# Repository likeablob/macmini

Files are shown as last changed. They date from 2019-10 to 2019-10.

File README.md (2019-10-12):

<p align="center">
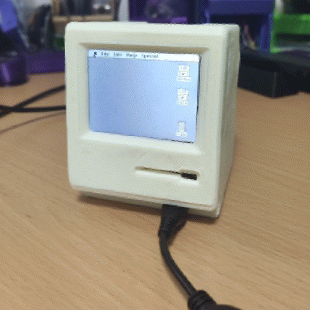
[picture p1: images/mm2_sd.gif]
  
</p>

# Mac(intosh) mini

## Build Instruction
- Print the outer shell.
  - PLA, 0.2 mm, 180 ℃ (See also [./openscad/README.md](./openscad/README.md))
  - `macintosh-mini-part-a.stl` ([stl](./openscad/macintosh-mini-part-a.stl))
  - `macintosh-mini-part-b.stl` ([stl](./openscad/macintosh-mini-part-b.stl))

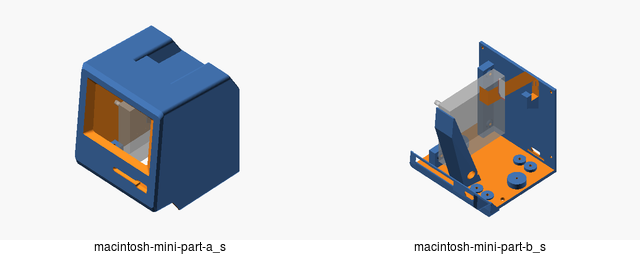
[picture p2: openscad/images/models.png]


- Setup your Orange Pi Zero Plus 2 (H3)
  - Install Armbian Bionic. https://www.armbian.com/orange-pi-zero-plus-2-h3/
  - Then SSH into the device.
```bash
$ sudo apt install -y git tightvncserver

# Install Node.js
$ git clone https://github.com/tj/n /tmp/n && cd /tmp/n && sudo make install
$ sudo n v10

# Install https://github.com/xpertsavenue/WiringOP-Zero
$ cd ~/
$ git clone https://github.com/xpertsavenue/WiringOP-Zero
## Please refer to https://github.com/xpertsavenue/WiringOP-Zero

# Enable SPI1 interface
$ sudo vi /boot/armbianEnv.txt # or use armbian-config
! overlays=spi-spidev analog-codec usbhost2 usbhost3
+ param_spidev_spi_bus=1

# Setup vncserver
$ mkdir ~/.vnc
$ vncpasswd ~/.vnc/passwd

# Install the dependencies & config files
$ git clone https://github.com/likeablob/macmini ~/macmini
$ cd ~/macmini
$ sudo ./install.sh

# Copy your assets
$ cp /path/to/vmac.rom ~/macmini/minivmac/vMac.ROM # Mini vMac ROM file
$ cp /path/to/vmac.dsk ~/macmini/minivmac/system.dsk # Mini vMac disk file
$ cp /path/to/.basilisk_ii_prefs ~/.basilisk_ii_prefs # Basilisk II config file
$ cp /path/to/macboot.wav ~/macmini/macboot.wav # Boot sound (optional)

# Reboot to apply the settings
$ sudo reboot now

# Select LineOut as the default sink
$ pacmd list-sinks | grep -e 'name:' -e 'index:'
  index: 0
	  name: <alsa_output.platform-1c22c00.codec.analog-mono> # LineOut
* index: 1
	  name: <alsa_output.platform-soc_sound.stereo-fallback> # HDMI
$ pactl set-default-sink 0 # or use `DISPLAY=:1 pavucontrol` and `alsamixer` to adjust volume
```
- [Tips]: Here is my working [.basilisk_ii_prefs](basilisk_ii_prefs.md).
  
- Wire the display & USB boards to the OPi

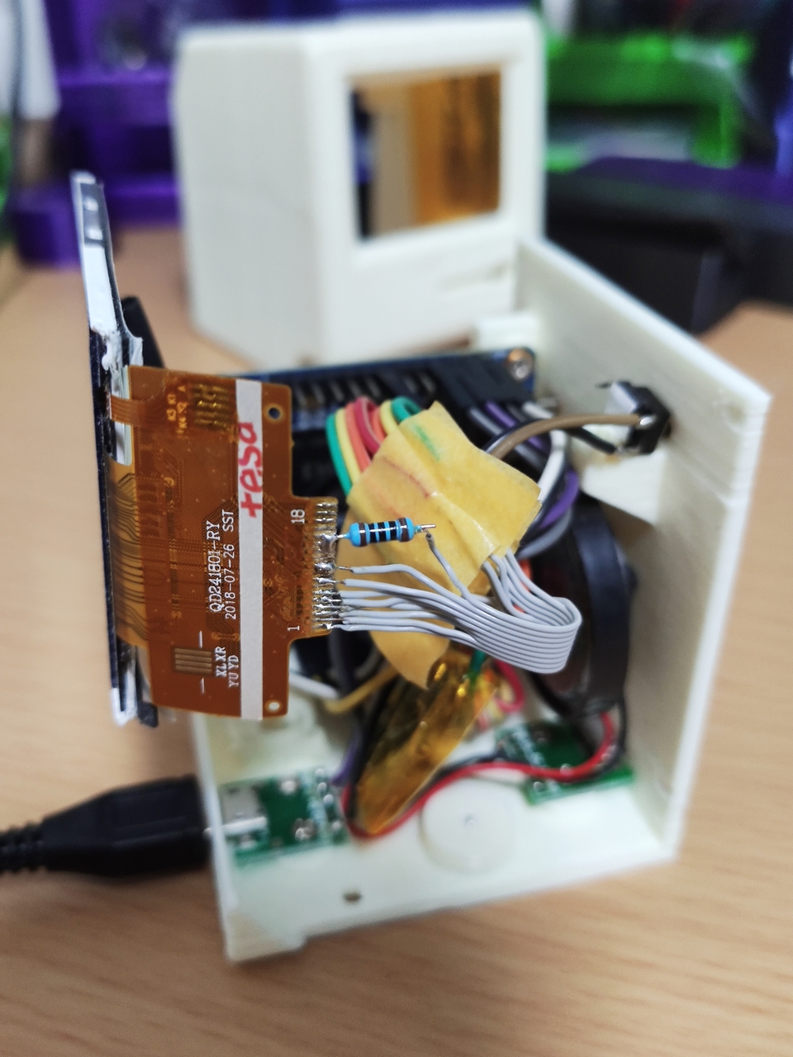
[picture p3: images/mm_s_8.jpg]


| OPi | Peripherals |
| --- | --- |
| PA15/SPI1_MOSI | LCD MOSI |
| PA16/SPI1_MISO | LCD MISO |
| PA14/SPI1_CLK  | LCD CLK |
| PA13/SPI1_CS | LCD CS |
| PS12 | LCD RESET |
| PA11 | LCD DC |
| PA06 | Push Switch |
| GND | Push Switch |
| USB-DP2 | USB (Front) Data+ |
| USB-DM2 | USB (Front) Data- |
| 5V | USB (Front/Rear) 5V |
| GND | USB (Front/Rear) GND |
| LINEOUTL | (Optional) Amplifier Input |

- [Tips]: Pinout can be found below.
  - OPiZero
    - https://linux-sunxi.org/Xunlong_Orange_Pi_Zero_Plus
    - http://www.orangepi.org/orangepibbsen/forum.php?mod=viewthread&tid=2236
  - LCD (Note that there might be some variants.)
    - [link1](https://www.solidrop.net/product/free-ship-5pc-lot-2-4inch-spi-tft-lcd-screen-18pin-240-320-color-lcd-drive-ic-ili9341-4io-only-for-stm32-mcu-raspberry-pi.html) [link2](https://github.com/myelin/tiny-tft/blob/master/TJC-024-9341-18-pin-SPI-240x320-ili9341-2.4-inch-touch/chinese-driver/TJC-024-9341.pdf)
    - [backup](./images/lcd-ili9341-pinout.jpg)

## Basic Concepts
1. At system boot, [`fbtft_device`](./config/fbtft.conf) kernel module is loaded and it initializes the LCD as `/dev/fb0`.
2. `nodm` starts an X session and `~/.xinitrc` get executed.
3. `~/.xinitrc` launchs `matchbox-window-manager` and `~/macmini/switcher/*js`.
4. `~/macmini/switcher/index.js` reads the scripts [`~/macmini/switcher/sh.d/*sh`](./switcher/sh.d/) and spawns them one by one when there is a HTTP GET request at `localhost:5501/`.
5. `~/macmini/switcher/gpio-reader.js` watchs the push SW at GPIO7(PA06) and send a request to `localhost:5501/`.

### How does the low-res LCD(320x240) handle 512x384 resolution?
Internally `tightvncserver` and `ssvncviewer` are used to scale the display.
- e.g. [`1_large_minimac.sh`](./switcher/sh.d/1_large_minimac.sh) launches: 
  -  `tightvncserver` to create a virtual display (512x384) at `DISPLAY=:1` (`:5901`)
  -  `minivmac` in `DISPLAY:1`
  -  `ssvncviewer -scale 0.625` in `DISPLAY:0` (By the `-scale` option, low-res LED get upscaled)

## Gallery
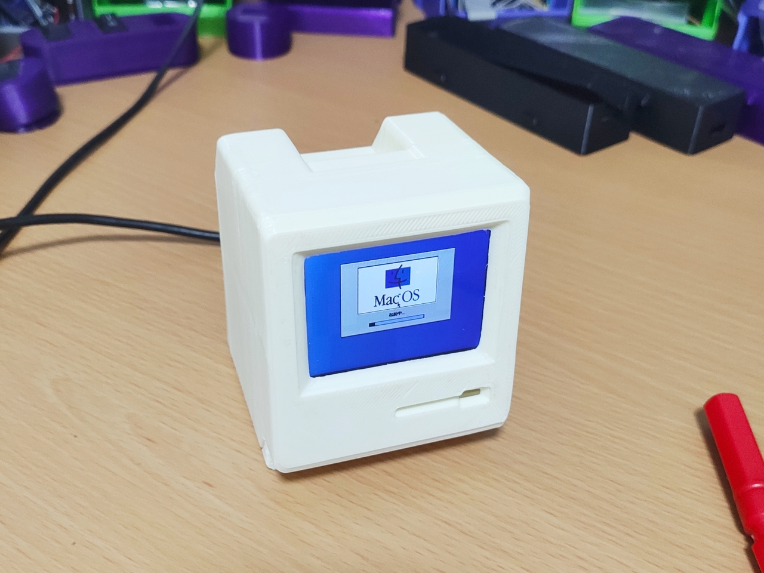
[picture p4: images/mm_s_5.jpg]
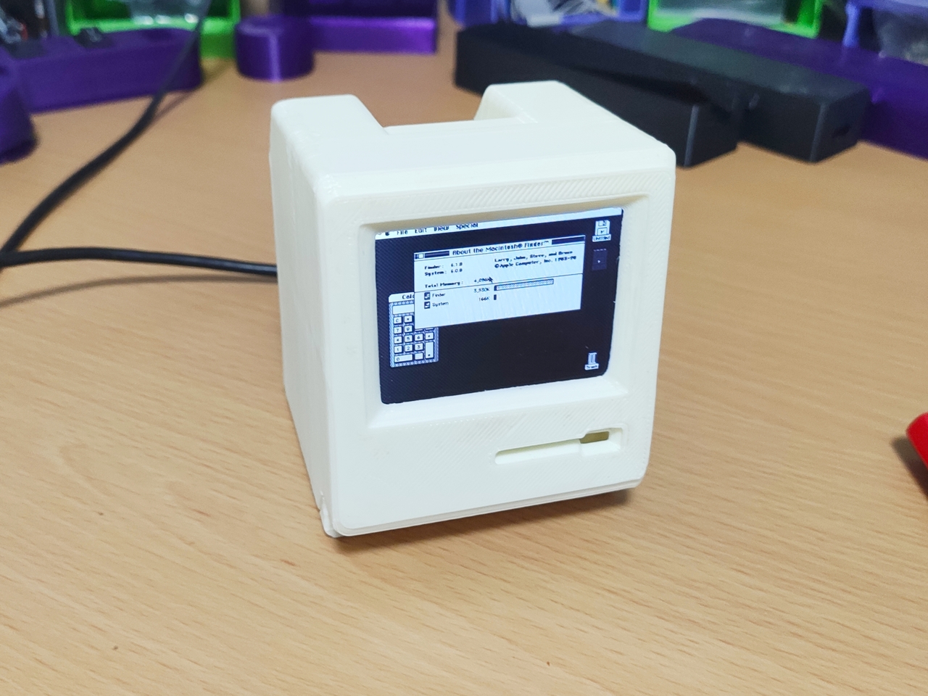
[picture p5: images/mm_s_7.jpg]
|   |   |
| :---: | :---: |
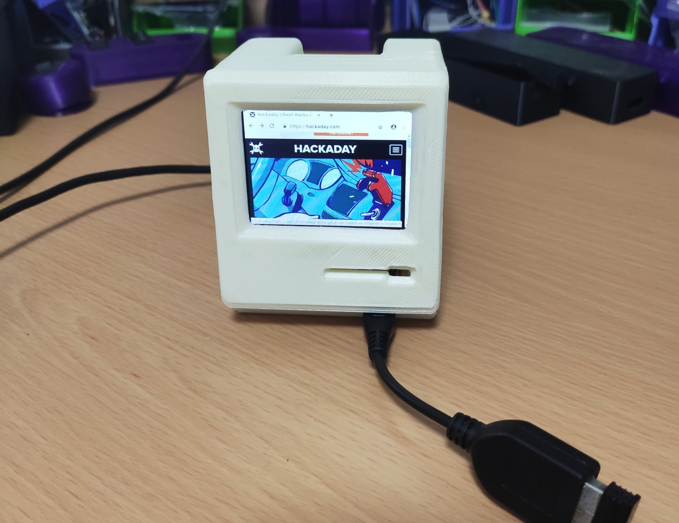
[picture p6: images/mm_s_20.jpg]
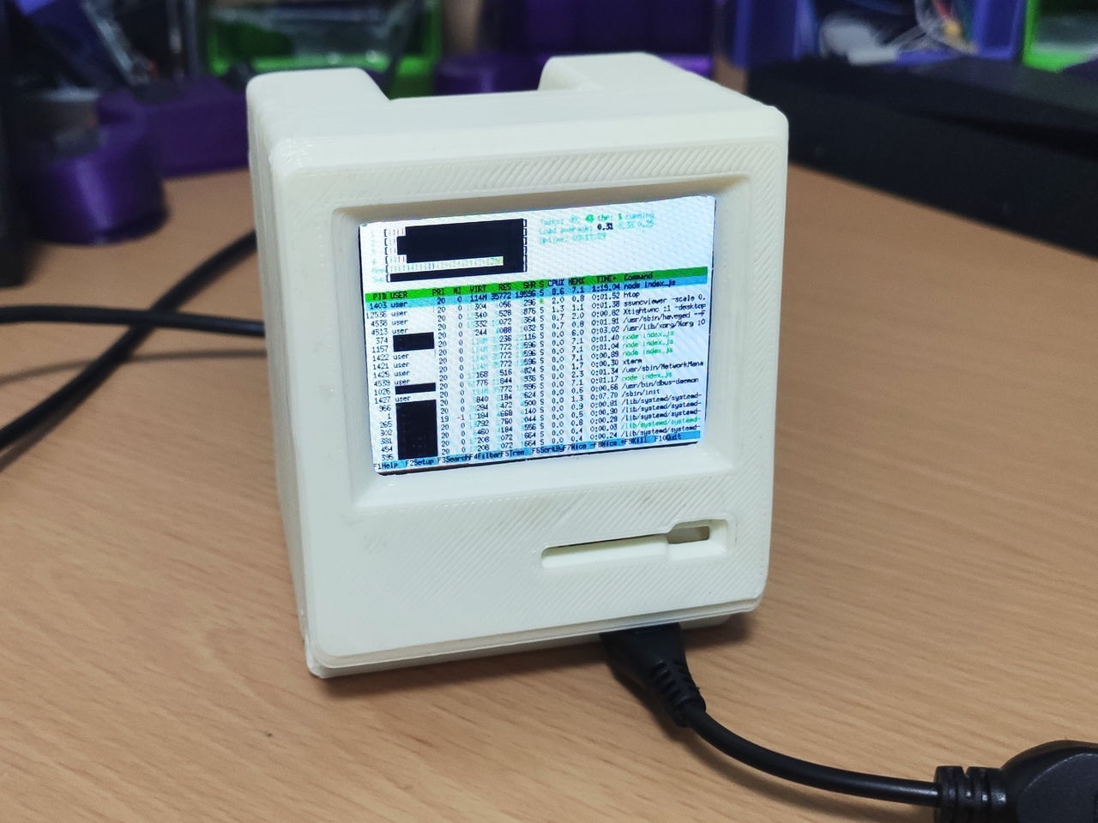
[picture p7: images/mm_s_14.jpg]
|  |  |
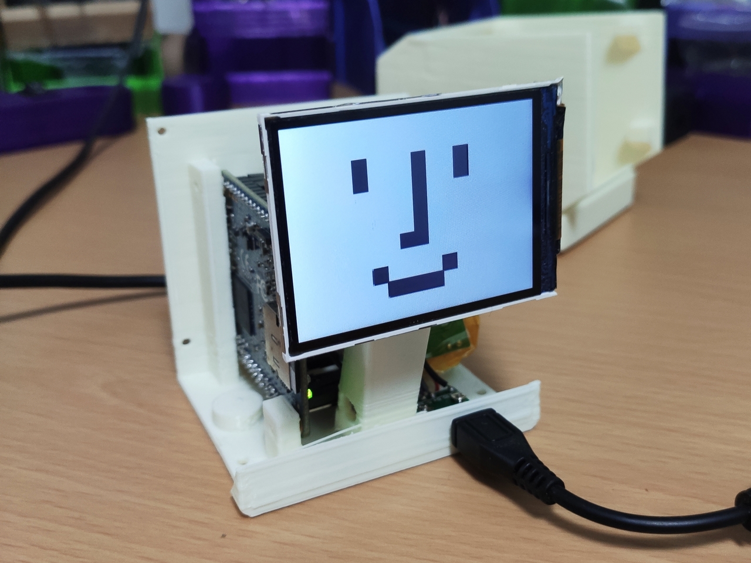
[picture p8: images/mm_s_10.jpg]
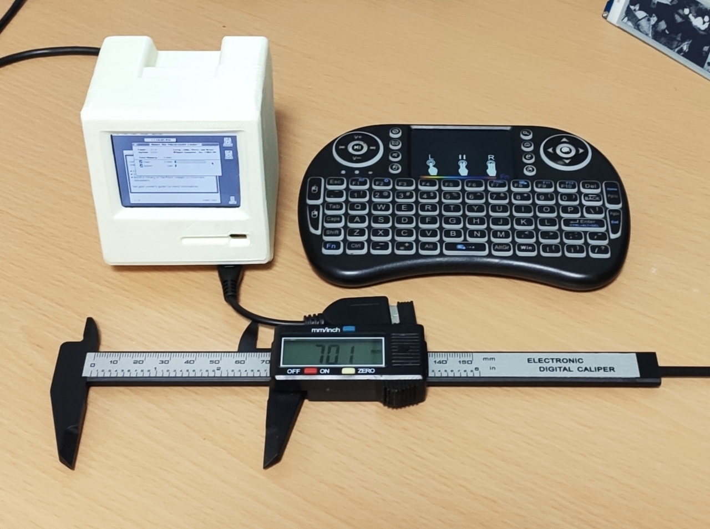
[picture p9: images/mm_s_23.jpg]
|  |  |
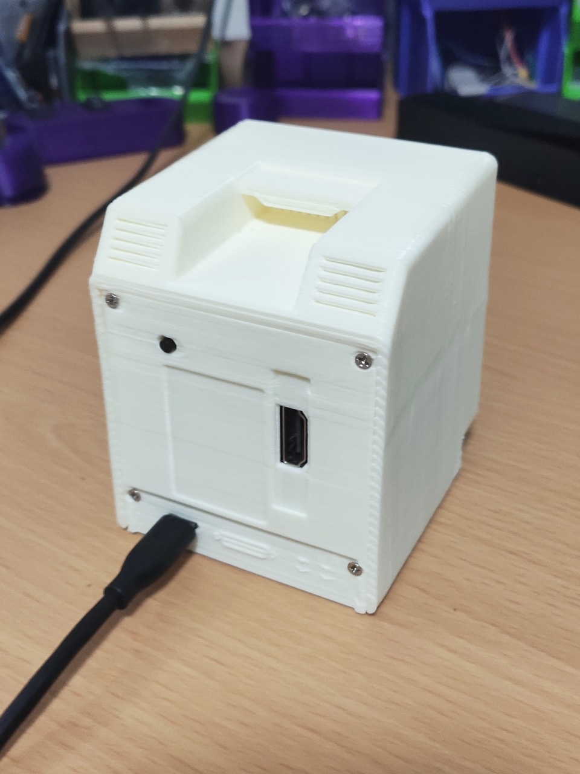
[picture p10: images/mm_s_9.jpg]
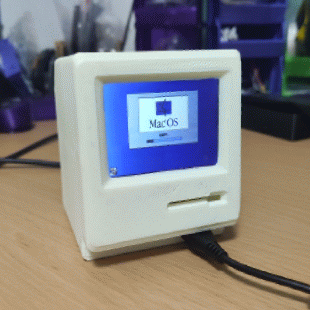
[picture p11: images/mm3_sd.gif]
|   |   |

## BOM
| Name | Quantity | Descriptions |
| --- | :---: | --- |
| OrangePi Zero Plus 2 (H3) | 1 | H5 ver. might work too. |
| 2.4inch SPI Display (ili9341, 320x240, with flat cable) | 1 | |
| Generic micro-USB Breakout Board | 2 | |
| M2 x 6 mm Self Tapping Screw | 16 | |
| D10mm Rounding Magnet | 2 | |
| 7x7 mm Push Switch | 1 | |
| 2W Small Speaker | 1 | (Optional) |
| ClassD Audio Amplifier Board | 1 | (Optional) PAM8403 |

## Acknowledgments
- Mini vMac https://www.gryphel.com/c/minivmac/
- Basilisk II https://basilisk.cebix.net/
- Kudos to all the devs!

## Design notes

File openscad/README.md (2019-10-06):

<p align="center">
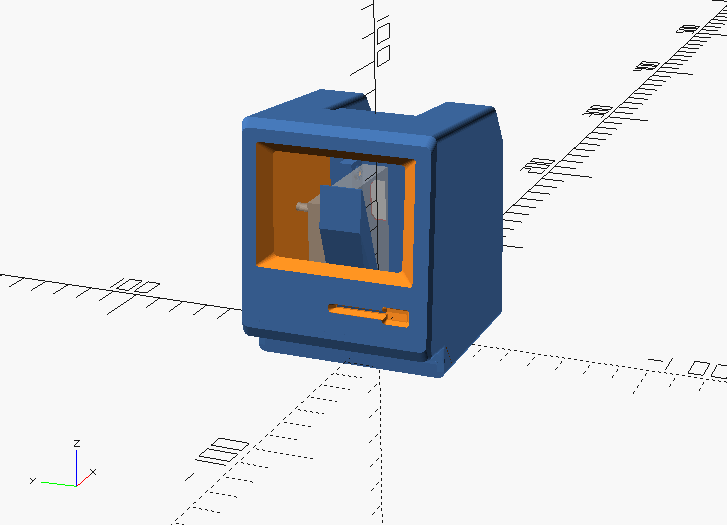
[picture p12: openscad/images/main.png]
  
</p>

## Print conditions
- PLA, 0.2 mm, 180 ℃
- `macintosh-mini-part-a`: Rotate so that the -X(front) side is facing down.



## Dependencies
- [OskarLinde]'s [scad-utils](https://github.com/OskarLinde/scad-utils)
- openscad-nightly (`20181009T230242.gitf3de0e27+2416.1`)

## Build
```sh
$ git submodule update --init --recursive # or git clone --recursive
$ make -j4
```

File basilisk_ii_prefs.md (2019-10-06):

~/.basilisk_ii_prefs
```bash
disk ${/path/to/disk1.dsk}
disk ${/path/to/disk2.dsk}
extfs ${/path/to/your/home/dir}
screen win/512/384
seriala /dev/ttyS5
serialb /dev/ttyS6
ether slirp
udptunnel false
udpport 6066
rom ${/path/to/mac.rom}
bootdrive 0
bootdriver 0
ramsize 33554432
frameskip 0
modelid 5
cpu 3
fpu false
nocdrom true
nosound false
noclipconversion false
nogui false
jit true
jitfpu true
jitdebug false
jitcachesize 2048
jitlazyflush true
jitinline true
keyboardtype 5
keycodes false
mousewheelmode 1
mousewheellines 3
dsp /dev/dsp
mixer /dev/mixer
idlewait true
```

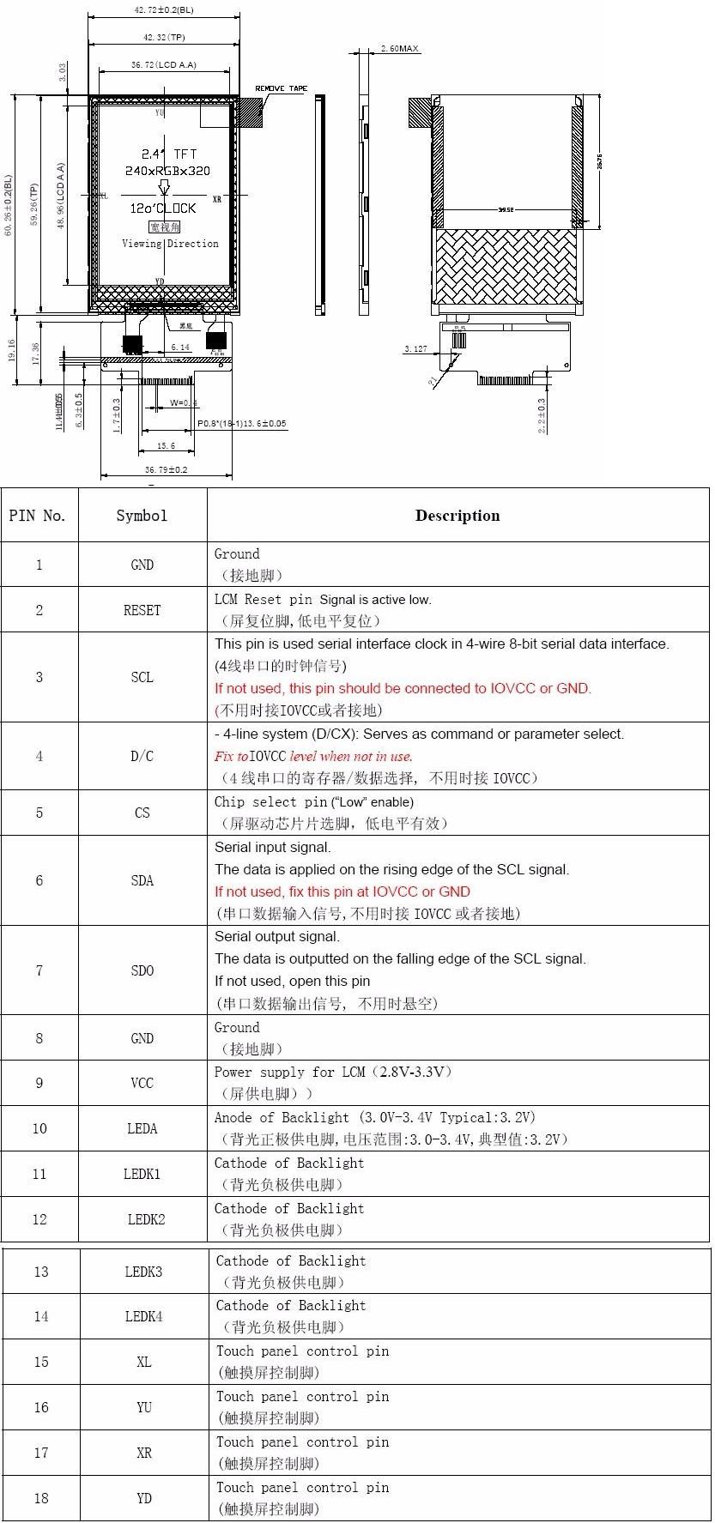
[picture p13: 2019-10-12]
images/lcd-ili9341-pinout.jpg

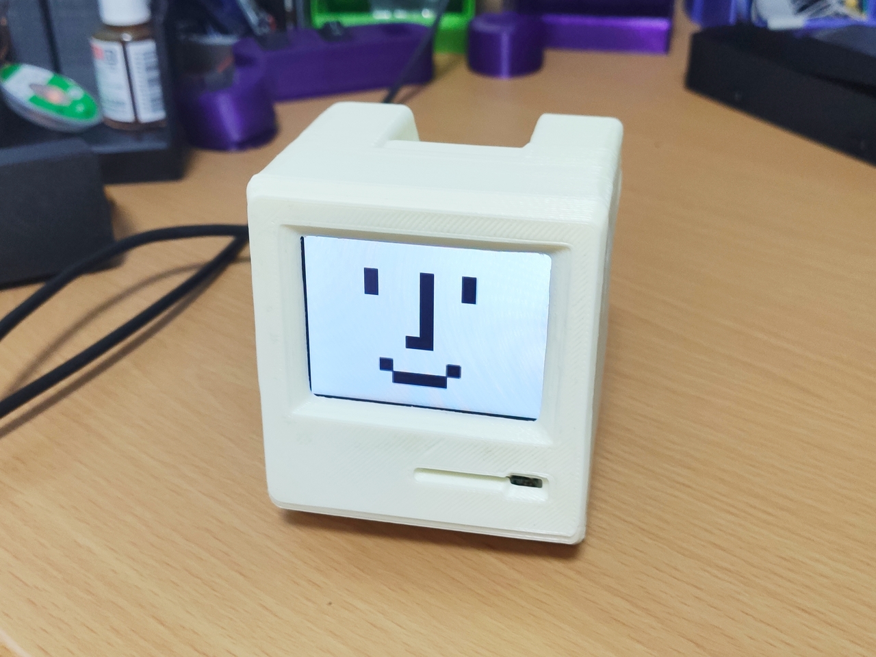
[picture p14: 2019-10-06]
images/mm_s_6.jpg

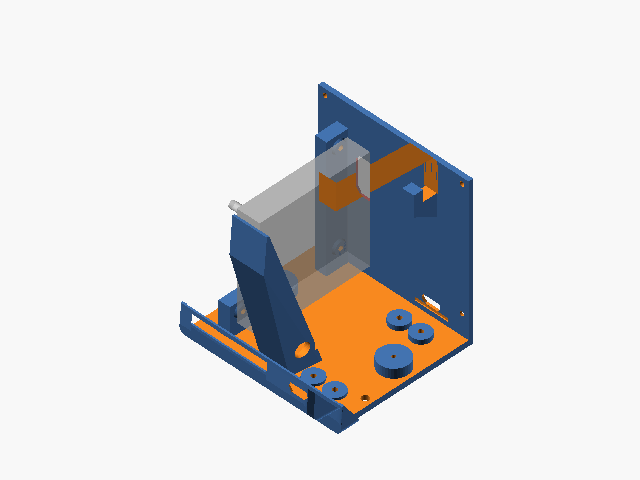
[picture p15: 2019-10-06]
openscad/images/macintosh-mini-part-b_s.png

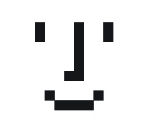
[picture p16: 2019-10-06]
images/macface.png

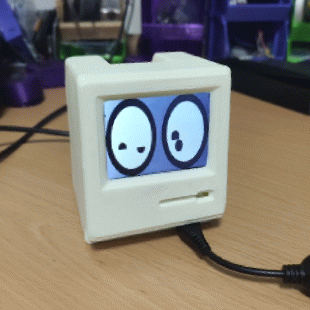
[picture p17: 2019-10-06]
images/mm1_sd.gif

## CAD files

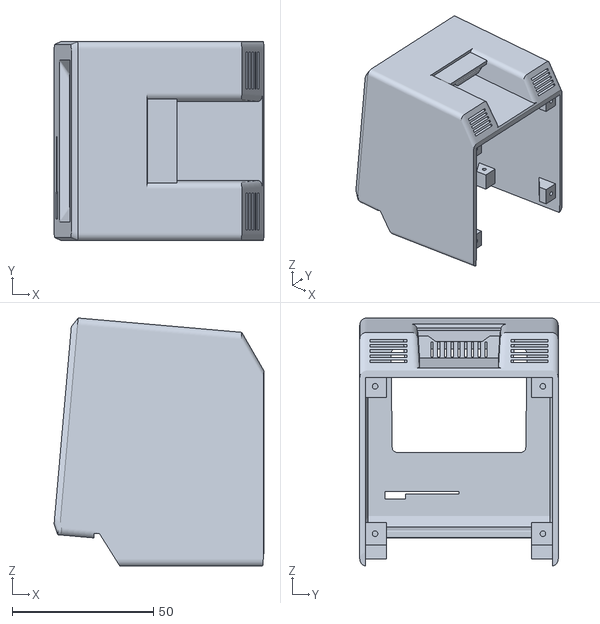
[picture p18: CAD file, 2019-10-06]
openscad/macintosh-mini-part-a.stl
74.3 x 70.3 x 87.8

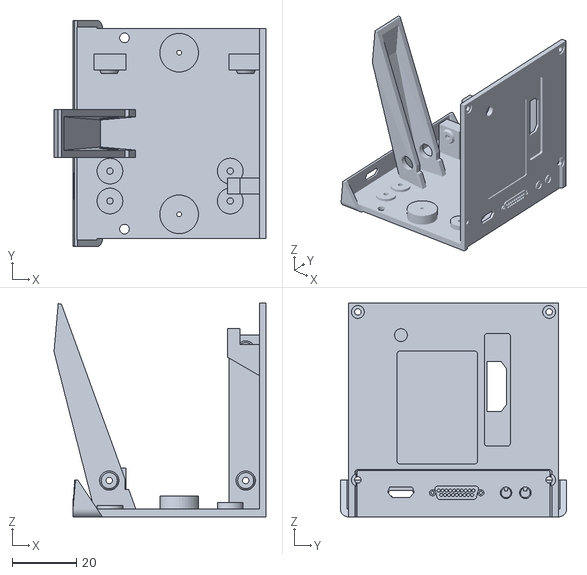
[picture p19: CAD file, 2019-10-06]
openscad/macintosh-mini-part-b.stl
65.9 x 70.3 x 66.5

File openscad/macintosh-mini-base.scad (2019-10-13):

$fn=40;
include <scad-utils/morphology.scad>

WH_RATIO = 22.7/29.2;
DH_RATIO = 46.0/63.4;

BODY_Z = 90;
BODY_X = BODY_Z * WH_RATIO;
BODY_Y = BODY_Z * DH_RATIO;

module copy_mirror(vec=[0,1,0]){
    children();
    mirror(vec) children();
}

module base(mscale=1) {
  difference() {
    hull() {
      // upper
      translate([0, 0, (BODY_X)/2 + (BODY_Z-BODY_X)/2])
      rotate([0, 5, 0])
      cube(size=[BODY_X, BODY_Y, BODY_X], center=true);

      // lower
      translate([0, 0, (BODY_Z-BODY_X)/2])
      cube(size=[BODY_X, BODY_Y, BODY_Z-BODY_X], center=true);

      // display
      rotate([0, 5, 0])
      translate([-BODY_X/2-6, 0, (BODY_Z-BODY_X)/2-1])
      translate([0, 0, BODY_X/2])
      cube(size=[0.1, BODY_Y*0.97, BODY_X*0.93], center=true);
    }

    // under the display
    minkowski() {
      UD_Z = (BODY_Z-BODY_X)/2*0.6;
      translate([-BODY_Y/2-10/2, 0, UD_Z-1.5])
      hull() {
        rotate([0, 5, 0])
        cube(size=[BODY_Y*0.2+10, BODY_Y+1, UD_Z*2], center=true);

        /* translate([BODY_Y*0.2/2+8, 0, -UD_Z])
        rotate([90, 0, 0])
        cylinder(d=0.01, h=BODY_Y+1, center=true); */
        translate([BODY_Y*0.2/2+1, 0, -UD_Z])
        rotate([90, 0, 0])
        cylinder(d=0.01, h=BODY_Y+1, center=true);
      }

      rotate([90, 0, 0])
      cylinder(d=1, h=10, center=true);
    }

    // top mizo
    translate([BODY_X*0.4, 0, BODY_Z-BODY_Z*0.27])
    rotate([0, 5, 0])
    scale([mscale, mscale, mscale])
    linear_extrude(height=BODY_Z*0.3, scale=1.1,  center=false, convexity=10, twist=0)
    square(size=[BODY_X, BODY_Y/2], center=true);

    // back edge
    translate([BODY_Y, 0, BODY_X/2 + BODY_Z*0.5])
    rotate([0, 60, 0])
    cube(size=[BODY_X, BODY_Y+3, BODY_X], center=true);

    // back
    translate([BODY_X/2+BODY_X*0.1/2-1, 0, (BODY_Z)/2])
    cube(size=[BODY_X*0.1, BODY_Y*1.2, BODY_Z], center=true);

    // side edge
    *copy_mirror([0,1,0])
    translate([-BODY_X/2, BODY_Y/2, 0])
    translate([0, 0, BODY_Z/2*1.1])
    rotate([0, 5, 0])
    rotate([0, 0, 60])
    cube(size=[5, 5, BODY_Z], center=true);
  }
}

THICK=-5;

// variables for partB
OPIZ_X = 48;
OPIZ_Y = 46;
OPIZ_Z = 10;

OPI_HOLE_POS = 2.8;

HDMI_Z=5.5;
HDMI_Y=15;

OPIZ_HLD_Z = BODY_Z*0.6;
OPIZ_HLD_Y = 5;
OPIZ_HLD_X = 10;

OPIZ_OFFSET_Z = 6;
OPIZ_OFFSET_X = -1.5;

BACKPANEL_X = 1.0;

module partB() {
  difference() {
    union() {
      difference() {
        intersection(){
          difference(){
            minkowski() {
              base();
              rotate([0, 90, 0])
              cylinder(d=5, h=0.01, center=true);
            }
            // inner space
            difference() {
              translate([-0.5, 0, 0])
              scale([0.95, 1, 1])
              resize([BODY_X-THICK, 0, 0], auto=[false, true, true])
              base(1.15);

              translate([BODY_X/2+10/2-3, 0, 0])
              cube(size=[10, BODY_Y*2, BODY_Z*2], center=true);
            }

            copy_mirror([0,1,0])
            translate([BODY_X/2-10, BODY_Y*0.91/2, BODY_Z*0.68])
            rotate([0, 90, 0]){
              screw(2);
              translate([0, 0, 8.5])
              screw(4);
            }

            copy_mirror([0,1,0])
            translate([BODY_X/2-10, BODY_Y*0.91/2, BODY_Z*0.1])
            rotate([0, 90, 0]){
              screw(2);
              translate([0, 0, 8.5])
              screw(4);
            }

            copy_mirror([0,1,0])
            translate([-BODY_X*0.2, BODY_Y*0.91/2, BODY_Z*0.1/3])
            union(){
              screwB(3);
              translate([0, 0, -15])
              screwB(4);
            }

          }

          // partB

          union() {
            H2 = (BODY_Z-BODY_X);
            Y=BODY_Y-THICK-4-1;
            // front
            hull() {
              translate([-(BODY_X/2 + BODY_Y*0.2)/2-1, 0, H2/2-2])
              cube(size=[1, Y+8, 2], center=true);

              translate([-(BODY_X/2 + BODY_Y*0.2)/2-1.3, 0, -2])
              cube(size=[2, Y+8, 2], center=true);

              translate([-(BODY_X/2)/2, 0, -4])
              cube(size=[2, Y+8, 2], center=true);
            }

            // bottom
            cube(size=[BODY_X, Y, BODY_X*0.1], center=true);

            // back
            translate([(BODY_X/2), 0, BODY_Z*0.75/2-1-0.3])
            cube(size=[BODY_X*0.2, Y, BODY_Z*0.70], center=true);
          }

        }

        // hdmi
        color("red")
        translate([BODY_X/2-OPIZ_X/2-3, BODY_Y/3.5, OPIZ_Y/2 + OPIZ_OFFSET_Z])
        rotate([90, 0, 0])
        translate([OPIZ_X/2+3, OPIZ_Y/2-HDMI_Y/2-6.5, 2.5])
        hdmi(0.3);

        // micro usb for power
        translate([BODY_X/2-USBM_BOARD[0]/2+OPIZ_OFFSET_X-1.1, -BODY_Y/4, 2])
        rotate([0, 0, 180])
        usbm_board(0.2);

        // micro usb for keyboards
        translate([-BODY_X*0.1-USBM_BOARD[0]/2-2, -BODY_Y/4,1])
        usbm_board(0.2);

        // switch
        translate([BODY_X/2, -BODY_Y/4, BODY_Z*0.6])
        rotate([0, 90, 0])
        linear_extrude(height=10, center=true, convexity=10, twist=0)
        circle(d=4);

      } // diff

      // opi holder
      translate([OPIZ_OFFSET_X, 0, 0])
      difference() {
        union() {
          translate([BODY_X/2-OPIZ_HLD_X/2-1, OPIZ_HLD_Y/2 + BODY_Y/3.5  + 1, OPIZ_HLD_Z/2])
          cube(size=[OPIZ_HLD_X, OPIZ_HLD_Y, OPIZ_HLD_Z], center=true);

          translate([BODY_X/2+OPIZ_HLD_X/2-5-OPIZ_X, OPIZ_HLD_Y/2 + BODY_Y/3.5  + 1, OPIZ_HLD_Z/4.5/2])
          cube(size=[OPIZ_HLD_X, OPIZ_HLD_Y, OPIZ_HLD_Z/4], center=true);

          // screw base A
          translate([BODY_X/2-OPIZ_X/2-3, BODY_Y/3.5, OPIZ_Y/2 + OPIZ_OFFSET_Z])
          rotate([90, 0, 0])
          mirror_y()
          translate([OPIZ_X/2-OPI_HOLE_POS, OPIZ_Y/2-OPI_HOLE_POS, -1])
          cylinder(d=6, h=1, d2=5, center=!true);

          // screw base B
          translate([BODY_X/2-OPIZ_X/2-3, BODY_Y/3.5, OPIZ_Y/2 + OPIZ_OFFSET_Z])
          rotate([90, 0, 0])
          mirror([1, 0, 0])
          mirror([0, 1, 0])
          translate([OPIZ_X/2-OPI_HOLE_POS, OPIZ_Y/2-OPI_HOLE_POS, -1])
          cylinder(d=6, h=1, d2=5, center=!true);
        }

        // screws A
        translate([BODY_X/2-OPIZ_X/2-3, BODY_Y/3.5, OPIZ_Y/2 + OPIZ_OFFSET_Z])
        rotate([90, 0, 0])
        mirror_y()
        translate([OPIZ_X/2-OPI_HOLE_POS, OPIZ_Y/2-OPI_HOLE_POS, -1])
        cylinder(d=2, h=10, center=true);

        // screws B
        translate([BODY_X/2-OPIZ_X/2-3, BODY_Y/3.5, OPIZ_Y/2 + OPIZ_OFFSET_Z])
        rotate([90, 0, 0])
        mirror([1, 0, 0])
        mirror([0, 1, 0])
        translate([OPIZ_X/2-OPI_HOLE_POS, OPIZ_Y/2-OPI_HOLE_POS, -1])
        cylinder(d=2, h=10, center=true);

      }

      // micro usb for power - screws
      translate([BODY_X/2-USBM_BOARD[0]/2+OPIZ_OFFSET_X-1.1, -BODY_Y/4, 0])
      rotate([0, 0, 180])
      usbm_board_screws(d=8, h=2, center=false);

      // micro usb for keyboards - screws
      translate([-BODY_X*0.1-USBM_BOARD[0]/2-2, -BODY_Y/4, 0])
      usbm_board_screws(d=8, h=1, center=false);

      // magnets - holder
      mirror_y()
      translate([7, BODY_Y/2.6, 0])
      cylinder(d=12, h=4, center=!true);
      } // union

      // micro usb for power
      translate([BODY_X/2-USBM_BOARD[0]/2+OPIZ_OFFSET_X-1.1, -BODY_Y/4, -2.2])
      rotate([0, 0, 180])
      usbm_board_screws(d=2, h=5, center=false);

      // micro usb for keyboards
      translate([-BODY_X*0.1-USBM_BOARD[0]/2-2, -BODY_Y/4, -2.2])
      usbm_board_screws(d=2, h=5, center=false);

      // magnets - holder
      mirror_y()
      translate([7, BODY_Y/2.6, -2.6]) {
        cylinder(d=11, h=3+0.01, center=!true);
        translate([0, 0, 3])
        cylinder(d=11, d2=3, h=2, center=!true);
      }

      // magnets - holder
      mirror_y()
      translate([7, BODY_Y/2.6, -2.6]) {
        cylinder(d=1.5, h=10, center=!true);
      }

      // back panel A
      color("red")
      translate([BODY_X/2+10/2-1-BACKPANEL_X, BODY_Y/3.5-5, OPIZ_Y/2+14])
      rotate([0, 90, 0])
      linear_extrude(height=10, center=true, convexity=10, twist=0)
      rounding(0.8)
      square(size=[35, 8], center=true);

      // back panel B
      color("red")
      translate([BODY_X/2+10/2-1-BACKPANEL_X, 0, 2])
      rotate([0, 90, 0])
      linear_extrude(height=10, center=true, convexity=10, twist=0, scale=1.2)
      rounding(0.8)
      square(size=[20, 60], center=true);

      // back panel C
      color("red")
      translate([BODY_X/2+10/2-1.5, -5, BODY_Z*0.35])
      rotate([0, 90, 0])
      linear_extrude(height=10, center=true, convexity=10, twist=0)
      rounding(0.8)
      square(size=[35, 25], center=true);

    }


    module pport(y=10, z=3) {
      rotate([0, 90, 0])
      linear_extrude(height=1.0, center=true, convexity=10, twist=0)
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

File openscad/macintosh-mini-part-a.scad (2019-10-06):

include <macintosh-mini-base.scad>

partA();

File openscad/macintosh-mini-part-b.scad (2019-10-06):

include <macintosh-mini-base.scad>

partB();

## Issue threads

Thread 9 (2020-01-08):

Resistor

pmar146, 2020-01-08:
The size of the resistor isn't clear in the image. Can you tell me what size you used?

likeablob, 2020-01-10:
@pmar146 Hi,  I'm using a 100 ohm resistor. That is a current-limiting resistor to adjust screen brightness, so the optimum value may vary.

pmar146, 2020-01-11:
Hi and thank your for the reply. I have printed the case and have a screen. Sadly my orange Pi is not the same as yours, so I am waiting on my new one to arrive. I love this little Mac. It is very cute.

________________________________
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

likeablob, 2020-01-11:
My pleasure.Thank you for your feedback :+1:
(I'd be happy if you could share the photos of your Mac.)

FYI, The Orange Pi used here is [`Orange Pi Zero +2 H3`](https://www.armbian.com/orange-pi-zero-plus-2-h3/). For `Orange Pi Zero +2 H5` (which has an arm64 CPU), you might need to recompile `minivmac`, at least.

pmar146, 2020-02-24:
Hi there again,
I got my new OPi last week. Sadly they sent an H5 instead of H3. You mentioned I need to recompile minivmac. I have followed all your project on my Opi and I see you have 2 minivmacs in the minivmac folder. I haven’t tried to run them yet. I have just copied all my assets to the folder and that is where I stopped on your project on GitHub. I am not sure where to turn next. I haven’t connected my lcd yet. Just ssh through putty to get the job done so far.

I tried to upload pictures of my one, but  I can’t put them on github. Where is the best place to post them.

Cheers and best wishes

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

likeablob, 2020-02-25:
@pmar146  Hi! Oops, I completely forgot to upload the source tarballs. Let me dig in my working dir...

Anyway, you can use the original author's [Mini vMac Variations Service](https://www.gryphel.com/c/minivmac/var_serv.html) to generate a tarball and follow [Build instruction](https://www.gryphel.com/c/minivmac/build.html) to compile it.

Also, even if pre-compiled `minivmac` doesn't run on your H5 OPiZero, the other shell scripts (apps) for example [sh.d/4_terminal.sh](https://github.com/likeablob/macmini/blob/master/switcher/sh.d/4_terminal.sh) probably work well. So you may see `xterm` launched once you've [correctly wired up the LCD and executed `install.sh`](https://github.com/likeablob/macmini#build-instruction). To debug these scripts, you might want to do as follows.

```bash
$ cd ~/macmini/switcher
$ npm start # Start `switcher` script manually
$ curl -v http://localhost:5501/ # Switch to a next script
or
$ cd ~/macmini/switcher/sh.d
$ sh 4_terminal.sh # The other scripts can be executed in the same way.
```

(BTW, to upload pictures, try to drag&drop a file to GitHub's comment box.

pmar146, 2020-02-25:
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

Here is my print of the case. I have been thoroughly enjoying this project.

likeablob, 2020-02-29:
@pmar146 Hi, I've finally pushed [the tarballs to here](https://github.com/likeablob/macmini/tree/master/minivmac).

Thank you. Nicely printed! (BTW, Have you printed `macintosh-mini-part-a.stl` (a upper part) upside down? That part can be printed w/o supports when it's rotated so that the -X(front) side is facing down.

pmar146, 2020-03-03:
Hi likeablob
I haven't printed the part that way round. I might give it a go when I get the pi sorted out. Thank you for the compliments too. Incidentally, this was the first print I have done with supports, so I am happy with it.

Thank you for posting the tar balls. I am downloading now.

I must compliment you on your soldering. This is not an easy thing to do on such a small ribbon cable.

Cheers and thanks

pmar146, 2020-03-03:
Hi likeablob
I haven't printed the part that way round. I might give it a go when I get the pi sorted out. Thank you for the compliments too. Incidentally, this was the first print I have done with supports, so I am happy with it.

Thank you for posting the tar balls. I am downloading now.

I must compliment you on your soldering. This is not an easy thing to do on such a small ribbon cable.

Cheers and thanks

pmar146, 2020-03-03:
I tried make the tarball on the 320x240 and got the following error:
gcc "src/MINEM68K.c" -o "bld/MINEM68K.o" -c -Wall -Wmissing-prototypes -Wno-uninitialized -Wundef -Wstrict-prototypes -Os
gcc "src/OSGLUXWN.c" -o "bld/OSGLUXWN.o" -c -Wall -Wmissing-prototypes -Wno-uninitialized -Wundef -Wstrict-prototypes -Os
In file included from src/OSGLUXWN.c:38:0:
src/CNFGRAPI.h:16:10: fatal error: X11/Xlib.h: No such file or directory
 #include <X11/Xlib.h>
          ^~~~~~~~~~~~
compilation terminated.
Makefile:12: recipe for target 'bld/OSGLUXWN.o' failed
make: *** [bld/OSGLUXWN.o] Error 1

I am not sure what I did wrong there.

likeablob, 2020-03-04:
@pmar146 Try to install `libx11-dev` by `sudo apt install libx11-dev`. And if you face similar problems, try to google `${header name} ubuntu` (in this case `X11/Xlib.h ubuntu`) or  [use `apt-file` command to determine a package name](https://stackoverflow.com/a/33499131).

Closed 2020-09-12.

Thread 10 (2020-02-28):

LCD Pins

pmar146, 2020-02-28:
Hi There,
I notice on the LCD, you use pins 8,10 and 13. These are the backlight pins on the LCD. Where do these plug in on the OPI? I was looking at the pinout guide, but can't trace them there.
Cheers and thanks

likeablob, 2020-02-29:
@pmar146 Hi, in my case, these pins are connected as follows.

| LCD Pin                | Connected to                 |
| ---------------------- | ---------------------------- |
| 8 (GND)                | GND                          |
| 9, 10 (LED Anode)      | 3.3V (from OPi)                         |
| 11 (LED Cathode)       | NC (to prevent solder bridge |
| 12,13,14 (LED Cathode) | GND (through 100 Ohm)        |

Closed 2020-09-12.

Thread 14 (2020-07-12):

Armbian Bionic

pmar146, 2020-07-12:
Hi Mr Likeablob,
Can you tell me where you got your copy of Armbian Bionic?
I can only find the minimal version of it and am having trouble with the WiringOP-Zero.
I eventually got the H3 board instead and everything installs OK and runs properly through the HDMI, but I can’t get the GPIO pins to operate properly.

I think it is to do with the WiringOP-Zero install not working properly on my Pi.

Cheers
Pmar146

likeablob, 2020-07-23:
Hi @pmar146 san, How have you been?

My copy of Armbian Bionic came from the official site. Let me share the details.

```bash
$ uname -a
Linux opiz2b 4.19.57-sunxi #5.90 SMP Fri Jul 5 17:58:43 CEST 2019 armv7l armv7l armv7l GNU/Linux

$ lsb_release -a
No LSB modules are available.
Distributor ID:	Ubuntu
Description:	Ubuntu 18.04.2 LTS
Release:	18.04
Codename:	bionic
```
Could you share what you got during WiringOP-Zero installation?
https://github.com/xpertsavenue/WiringOP-Zero

pmar146, 2020-07-24:
Hi Likeablob,
I have been well and hope you are too. A lot of the delays in my project have been to shipping delays during Covid, but we are getting there. So  I got the Armbian Bionic from the official site too, but they only seem to offer a minimal version at the armbian site. Hence VI text editor isn't installed natively and even "Make" has to be installed natively. I notice there are a lot of dependancies missing to do the xpertsavenue/WiringOP-Zero. I added some, but am not sure if I am missing more.

Here are my details of the armbian install
minimac@orangepizeroplus2-h3:~$ uname -a
Linux orangepizeroplus2-h3 5.4.45-sunxi #20.05.3 SMP Wed Jun 10 12:09:20 CEST 2020 armv7l armv7l armv7l GNU/Linux
minimac@orangepizeroplus2-h3:~$ lsb_release -a
No LSB modules are available.
Distributor ID:	Ubuntu
Description:	Ubuntu 18.04.4 LTS
Release:	18.04
Codename:	bionic
minimac@orangepizeroplus2-h3:~$

AndI try to do a install on the WiringOP-Zero:
minimac@orangepizeroplus2-h3:~$ cd WiringOP-Zero
minimac@orangepizeroplus2-h3:~/WiringOP-Zero$ chmod +x ./build
minimac@orangepizeroplus2-h3:~/WiringOP-Zero$ sudo ./build
[sudo] password for minimac:
./build: 4: ./build: [[: not found
wiringPi Build script
=====================

WiringPi Library
[UnInstall]
make: Nothing to be done for 'all'.
[Install Headers]
[Install Dynamic Lib]

WiringPi Devices Library
[UnInstall]
make: Nothing to be done for 'all'.
[Install Headers]
[Install Dynamic Lib]

GPIO Utility
make: Nothing to be done for 'all'.
[Install]

All Done.

NOTE: To compile programs with wiringBP v2, you need to add:
    -lwiringPi
  to your compile line(s) To use the Gertboard, MaxDetect, etc.
  code (the devLib), you need to also add:
    -lwiringPiDev
  to your compile line(s).

I also note that my paced produces a different index:1 to  yours
minimac@orangepizeroplus2-h3:~/WiringOP-Zero$ pacmd list-sinks | grep -e 'name:' -e 'index:'
    index: 0
	name: <alsa_output.platform-1c22c00.codec.analog-mono>
  * index: 1
	name: <alsa_output.platform-sound.stereo-fallback>

pmar146, 2020-07-24:
The Pi starts and loads MiniVMac through the HDMI cable perfectly albeit without sound, but I just have to find a way to send it all through the GPIO pins.

This is an awesome project though. I have learnt so much by doing it.

Thank you for all your help.

pmar146, 2020-07-26:
I should mention,
That I now have the lcd lighting up when I turn on the pi, but still nothing is outputted to the screen,

I feel that the outputs are just not turned on to the gpio pins. Although, we are outputting volts to turn on the screen.

Pmar146

likeablob, 2020-07-26:
Hi @pmar146
Yeah, the minimal version is fine, I guess.  (Oh, nice, I just noticed they have released Armbian Forcal.)

> ./build: 4: ./build: [[: not found

Hmm, that's weird. But at least the output related to `GPIO Utility` (`gpio` command) looks fine.
Internally, this project uses that command just for reading the GPIO state of the push switch at PA06. In other words, LCD and Audio outputs does not depend on WiringPi-Zero.
```bash
$ gpio readall
+-----+-----+----------+------+--Orange Pi Zero--+------+----------+-----+-----+
| H2+ | wPi |   Name   | Mode | V | Physical | V | Mode | Name     | wPi | H2+ |
+-----+-----+----------+------+---+----++----+---+------+----------+-----+-----+
|     |     |     3.3v |      |   |  1 || 2  |   |      | 5v       |     |     |
|  12 |   8 |    SDA.0 |  OUT | 1 |  3 || 4  |   |      | 5V       |     |     |
|  11 |   9 |    SCL.0 |  OUT | 1 |  5 || 6  |   |      | 0v       |     |     |
|   6 |   7 |   GPIO.7 |   IN | 1 |  7 || 8  | 0 | ALT5 | TxD3     | 15  | 198 |
|     |     |       0v |      |   |  9 || 10 | 0 | ALT5 | RxD3     | 16  | 199 |
|   1 |   0 |     RxD2 | ALT3 | 0 | 11 || 12 | 0 | ALT3 | GPIO.1   | 1   | 7   |
|   0 |   2 |     TxD2 | ALT3 | 0 | 13 || 14 |   |      | 0v       |     |     |
|   3 |   3 |     CTS2 | ALT3 | 0 | 15 || 16 | 0 | ALT3 | GPIO.4   | 4   | 19  |
|     |     |     3.3v |      |   | 17 || 18 | 0 | ALT3 | GPIO.5   | 5   | 18  |
|  15 |  12 |     MOSI | ALT5 | 0 | 19 || 20 |   |      | 0v       |     |     |
|  16 |  13 |     MISO | ALT5 | 0 | 21 || 22 | 0 | ALT3 | RTS2     | 6   | 2   |
|  14 |  14 |     SCLK | ALT5 | 0 | 23 || 24 | 0 | ALT5 | CE0      | 10  | 13  |
|     |     |       0v |      |   | 25 || 26 | 0 | ALT3 | GPIO.11  | 11  | 10  |
+-----+-----+----------+------+---+---LEDs---+---+------+----------+-----+-----+
|  17 |  30 | STAT-LED |  OUT | 0 | 27 || 28 |   |      | PWR-LED  |     |     |
+-----+-----+----------+------+---+-----+----+---+------+----------+-----+-----+
| H2+ | wPi |   Name   | Mode | V | Physical | V | Mode | Name     | wPi | H2+ |
+-----+-----+----------+------+--Orange Pi Zero--+---+------+---------+-----+--+

# You can ensure the wiring as follows;
$ gpio read 7
1
$ gpio read 7
0 # While pushing the switch
```

> That I now have the lcd lighting up when I turn on the pi, but still nothing is outputted to the screen,
OK, could you check the following points w/o HDMI?
```bash
# Are the required kernel modules loaded properly?
$ lsmod | grep fb
fb_ili9340             16384  2
fbtft_device           40960  0
fbtft                  28672  2 fbtft_device,fb_ili9340

# Is Xorg running?
$ pgrep -af X
823 /usr/lib/xorg/Xorg :0 -nolisten tcp vt7
1057 /bin/sh -l -c /etc/X11/Xsession
9924 Xtightvnc :1 -desktop X -auth /home/user/.Xauthority -geometry 320x240 -depth 24 -rfbwait 120000 -rfbauth ...

# Is spidev configured correctly?
$ cat /boot/armbianEnv.txt
overlays=spi-spidev analog-codec usbhost2 usbhost3
param_spidev_spi_bus=1

# Is fbtft configured correctly?
$ cat /etc/modprobe.d/fbtft.conf
options fbtft_device custom name=fb_ili9340 gpios=dc:11,reset:12 speed=64000000 busnum=1 rotate=270 bgr=1
```

pmar146, 2020-07-27:
Hi Likeablob,
I see there is a problem with the WiringPI and also the command for the kernel modules came up with noting on my pi. I reckon that this should be the problem? What do you think?

minimac@orangepizeroplus2-h3:~$ gpio read 7

gpio: error while loading shared libraries: /usr/local/lib/libwiringPi.so: file too short

minimac@orangepizeroplus2-h3:~$ lsmod | grep fb

minimac@orangepizeroplus2-h3:~$

minimac@orangepizeroplus2-h3:~$ pgrep -af X

740 /usr/lib/xorg/Xorg :0 -nolisten tcp vt7

1157 /bin/sh -l -c /etc/X11/Xsession

1381 Xtightvnc :1 -desktop X -auth /home/minimac/.Xauthority -geometry 512x384 -depth 24 -rfbwait 120000 -rfbauth /home/minimac/.vnc/passwd -rfbport 5901 -fp /usr/share/fonts/X11/misc/,/usr/share/fonts/X11/Type1/,/usr/share/fonts/X11/75dpi/,/usr/share/fonts/X11/100dpi/ -co /etc/X11/rgb

minimac@orangepizeroplus2-h3:~$ cat /boot/armbianEnv.txt

verbosity=1

logo=disabled

console=both

disp_mode=1920x1080p60

overlay_prefix=sun8i-h3

overlays=spi-spidev analog-codec usbhost2 usbhost3

rootdev=UUID=fcbc9174-45c2-4540-a9bd-277840a614e1

rootfstype=ext4

param_spidev_spi_bus=1

usbstoragequirks=0x2537:0x1066:u,0x2537:0x1068:u

minimac@orangepizeroplus2-h3:~$ cat /etc/modprobe.d/fbtft.conf

options fbtft_device custom name=fb_ili9340 gpios=dc:11,reset:12 speed=64000000 busnum=1 rotate=270 bgr=1

minimac@orangepizeroplus2-h3:~$ lsmod | grep fb

The rest looks about right.
Cheers
PMAR146

________________________________
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

likeablob, 2020-07-27:
@pmar146

> `gpio: error while loading shared libraries: /usr/local/lib/libwiringPi.so: file too short`

For this, what will you get from the following?
```bash
$ ls -hl  /usr/local/lib/libwiringPi.so*
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
pmar146, 2020-08-17:
Hi  Likeablob,
I have checked all my wiring and downgraded the kernel to the same one as you. Amazingly I am finally getting some results from the commands above which are similar to yours. The push switch works. The LCD lights up, but nothing appears on it.

These are the answers to the checks you requested in a previous post.
`minimac@orangepizeroplus2-h3:~$ gpio readall
+-----+-----+----------+------+--Orange Pi Zero--+------+----------+-----+-----+
| H2+ | wPi |   Name   | Mode | V | Physical | V | Mode | Name     | wPi | H2+ |
+-----+-----+----------+------+---+----++----+---+------+----------+-----+-----+
|     |     |     3.3v |      |   |  1 || 2  |   |      | 5v       |     |     |
|  12 |   8 |    SDA.0 |  OUT | 1 |  3 || 4  |   |      | 5V       |     |     |
|  11 |   9 |    SCL.0 |  OUT | 1 |  5 || 6  |   |      | 0v       |     |     |
|   6 |   7 |   GPIO.7 |   IN | 1 |  7 || 8  | 0 | ALT5 | TxD3     | 15  | 198 |
|     |     |       0v |      |   |  9 || 10 | 0 | ALT5 | RxD3     | 16  | 199 |
|   1 |   0 |     RxD2 | ALT3 | 0 | 11 || 12 | 0 | ALT3 | GPIO.1   | 1   | 7   |
|   0 |   2 |     TxD2 | ALT3 | 0 | 13 || 14 |   |      | 0v       |     |     |
|   3 |   3 |     CTS2 | ALT3 | 0 | 15 || 16 | 0 | ALT3 | GPIO.4   | 4   | 19  |
|     |     |     3.3v |      |   | 17 || 18 | 0 | ALT3 | GPIO.5   | 5   | 18  |
|  15 |  12 |     MOSI | ALT5 | 0 | 19 || 20 |   |      | 0v       |     |     |
|  16 |  13 |     MISO | ALT5 | 0 | 21 || 22 | 0 | ALT3 | RTS2     | 6   | 2   |
|  14 |  14 |     SCLK | ALT5 | 0 | 23 || 24 | 0 | ALT5 | CE0      | 10  | 13  |
|     |     |       0v |      |   | 25 || 26 | 0 | ALT3 | GPIO.11  | 11  | 10  |
+-----+-----+----------+------+---+---LEDs---+---+------+----------+-----+-----+
|  17 |  30 | STAT-LED |  OUT | 0 | 27 || 28 |   |      | PWR-LED  |     |     |
+-----+-----+----------+------+---+-----+----+---+------+----------+-----+-----+
| H2+ | wPi |   Name   | Mode | V | Physical | V | Mode | Name     | wPi | H2+ |
+-----+-----+----------+------+--Orange Pi Zero--+---+------+---------+-----+--+
minimac@orangepizeroplus2-h3:~$ lsmod | grep fb
fb_ili9340             16384  1
fbtft_device           40960  0
fbtft                  28672  2 fbtft_device,fb_ili9340
minimac@orangepizeroplus2-h3:~$ Is Xorg running?
-bash: Is: command not found
minimac@orangepizeroplus2-h3:~$ pgrep -af X
741 /usr/lib/xorg/Xorg :0 -nolisten tcp vt7
1252 /bin/sh -l -c /etc/X11/Xsession
1412 Xtightvnc :1 -desktop X -auth /home/minimac/.Xauthority -geometry 512x384 -depth 24 -rfbwait 120000 -rfbauth /home/minimac/.vnc/passwd -rfbport 5901 -fp /usr/share/fonts/X11/misc/,/usr/share/fonts/X11/Type1/,/usr/share/fonts/X11/75dpi/,/usr/share/fonts/X11/100dpi/ -co /etc/X11/rgb
minimac@orangepizeroplus2-h3:~$ cat /boot/armbianEnv.txt
verbosity=1
logo=disabled
console=both
disp_mode=1920x1080p60
overlay_prefix=sun8i-h3
overlays=spi-spidev analog-codec usbhost2 usbhost3
rootdev=UUID=fcbc9174-45c2-4540-a9bd-277840a614e1
rootfstype=ext4
param_spidev_spi_bus=1
extraargs="fbcon=map:8"
usbstoragequirks=0x2537:0x1066:u,0x2537:0x1068:u
minimac@orangepizeroplus2-h3:~$ cat /etc/modprobe.d/fbtft.conf
options
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

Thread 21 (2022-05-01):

Question Regarding This Project In Terms Of Scalability

SamuelBanya, 2022-05-01:
Hey there,

You got a cool project here, and I'm wondering the following since I have zero clue about 3D printing:
How hard is it to scale this up to the actual Macintosh dimensions to have a 3D printed case that would be analogous to the actual Macintosh's size?

I was debating doing this exact project but to retro-fit a way bigger monitor or LCD screen instead of going for the mini route.

Was going to find if someone online would do this for me and then charge to send the case itself to me since I don't have a 3D printer, etc.

Thanks for reading my question :)

Sincerely,

Sam

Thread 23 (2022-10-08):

Other versions of Armbian

pmar146, 2022-10-08:
Hi Likaeblob,
It has been a few years since I played with this project. My sd card ended up corrupting and so I went to make a new one.

We can't seem to get Armbian Bionic anymore. More specifically the version used to do the minimac. I recall having all sorts of trouble with other versions when I tried in the beginning.

I have recently tried all other flavours of Armbian to remake the minimac image. In particular Armbian Focal.

Sadly I just can't seem to get it to work.

Do you have any suggestions?

Best Regards
PMAR146

lamerjack, 2024-01-16:
I had similar issue with Nanopi Neo and his oled display (that wasn't spi was I2c)
To make it work i had to run armbian-config
system->hardware and enable i2c0
you can try to enable spi instead of i2c
In my nanopi i have:
spi-add-cs1
spi-jedec-nor
spi-spidevdev

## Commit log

2019-10-13 Remove unused includes
    [macintosh-mini-base.scad]
2020-03-14 Bump acorn from 7.1.0 to 7.1.1 in /switcher
    Bumps [acorn](https://github.com/acornjs/acorn) from 7.1.0 to 7.1.1.
    - [Release notes](https://github.com/acornjs/acorn/releases)
    - [Commits](https://github.com/acornjs/acorn/compare/7.1.0...7.1.1)
